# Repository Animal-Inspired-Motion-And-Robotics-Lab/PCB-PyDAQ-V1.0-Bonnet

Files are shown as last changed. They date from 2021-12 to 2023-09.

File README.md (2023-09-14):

# Raspberry Pi Data Conversion Board (ADC, DAC, PWM)

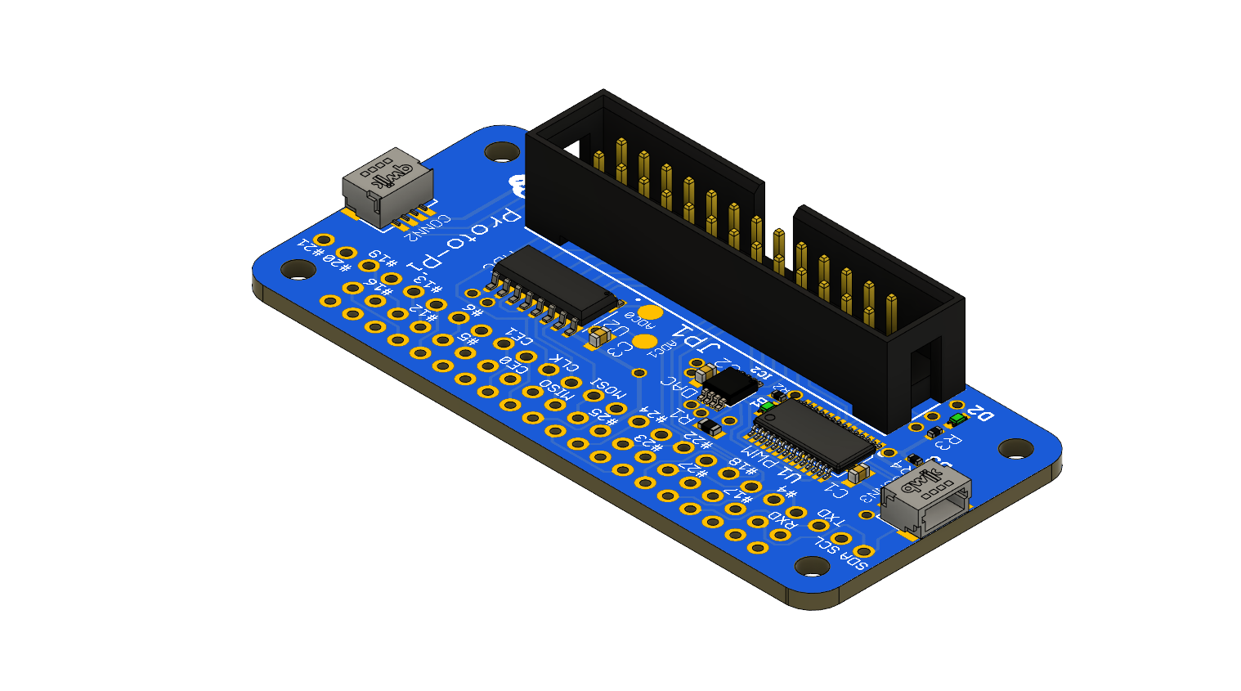
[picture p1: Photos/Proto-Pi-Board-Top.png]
<br/>
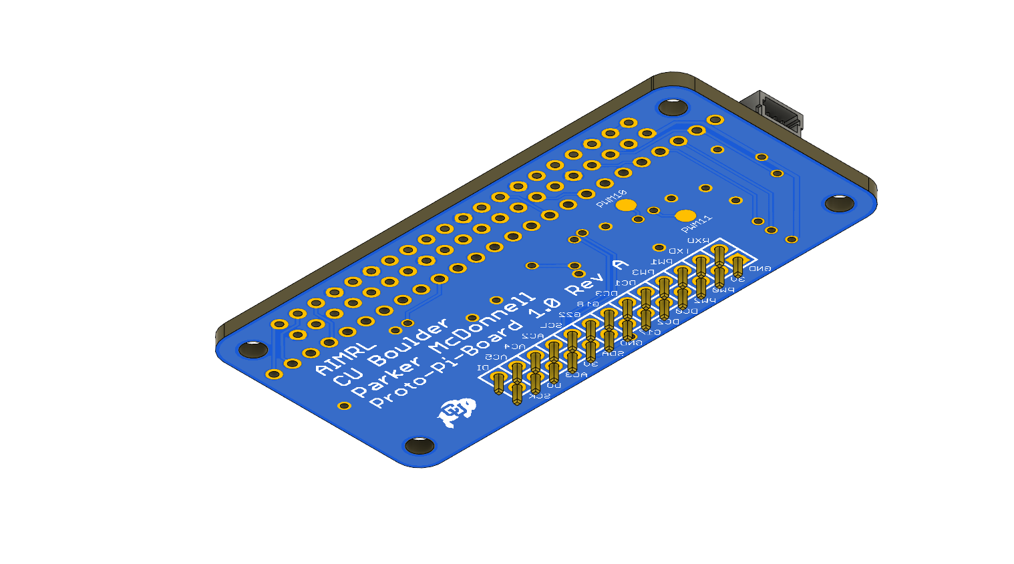
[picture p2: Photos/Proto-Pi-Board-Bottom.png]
<br/>

## Description

This board turns your Raspberry Pi into a prototyping powerhouse!  Now your Raspberry Pi can both read and generate analog voltages, in addition to driving PWM waveforms all using existing Python libraries! This repository includes all design files needed to immediately order and assemble the board or make further modifications!

## Features

- 26 Pin IDC Connector for easy prototyping
- 2x STEMMA QT compatible connectors (I2C, +3.3V and GND)
- 4x 12 bit ADC, DAC and PWM channels
- Easy access to SPI, I2C, UART and GPIO
- 2x general purpose PWM controlled LEDs 

## Pinout

### JP1 Connector Pinout <br/> <br/>

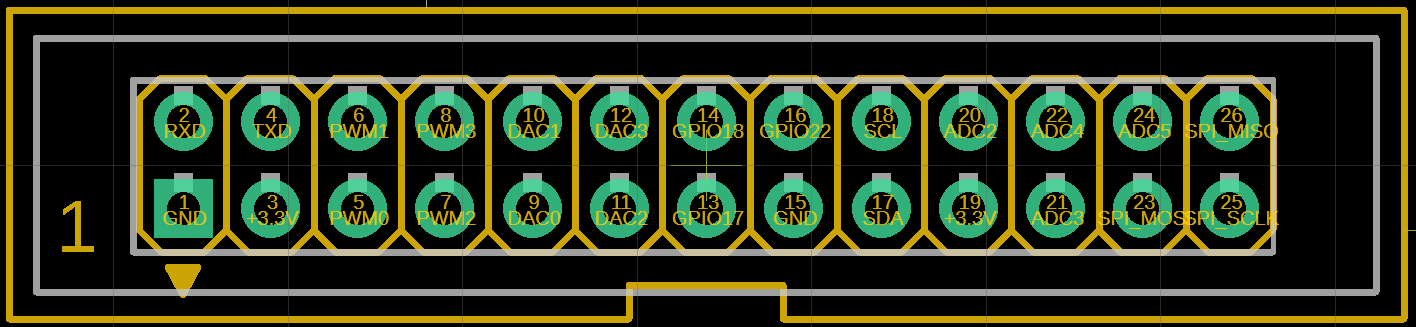
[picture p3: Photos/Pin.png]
<br/> <br/>

| Pin | Signal
| --- | --- |
|1	|GND|
|2	|RXD 
|3	|+3.3V 
|4	|TXD | 
|5	|PWM0
|6	|PWM1
|7	|PWM2
|8	|PWM3
|9	|DAC0
|10	|DAC1
|11	|DAC2
|12	|DAC3
|13	|GPIO17
|14	|GPIO18
|15	|GND
|16	|GPIO22
|17	|SDA
|18	|SCL
|19	|+3.3V
|20	|ADC2
|21	|ADC3
|22	|ADC4
|23	|SPI_MOSI
|24	|ADC5
|25	|SPI_SCLK
|26	|SPI_MISO

## Python Drivers <br/> <br/>

The Proto-Pi board uses Python based drivers to control the ADC, DAC and PWM integrated circuits.  Make sure to install the Adafruit CircuitPython, and required dependencies [(instructions)](https://learn.adafruit.com/circuitpython-on-raspberrypi-linux/installing-circuitpython-on-raspberry-pi) before installing the following drivers: 

- [MCP4728](https://github.com/adafruit/Adafruit_CircuitPython_MCP4728) (12-bit, Quad DAC)
- [MCP3008](https://pypi.org/project/adafruit-circuitpython-mcp3xxx/ )  (10-bit, 8-Channel ADC )
- [PCA9685](https://github.com/adafruit/Adafruit_CircuitPython_PCA9685) (12-bit, 16-Channel PWM)

## Datasheets!

- [MCP4728](http://ww1.microchip.com/downloads/en/devicedoc/22187e.pdf) (12-bit, Quad DAC)
- [MCP3008](https://ww1.microchip.com/downloads/en/DeviceDoc/21295d.pdf)  (10-bit, 8-Channel ADC )
- [PCA9685](https://www.nxp.com/docs/en/data-sheet/PCA9685.pdf) (12-bit, 16-Channel PWM)

## License

The original board shape and connector pinout was based on the amazing [Adafruit Prototype Bonnet](https://www.adafruit.com/product/3203). Thanks Adafruit!

This work is licensed under the Creative Commons Attribution-ShareAlike 4.0 International License. To view a copy of this license, visit http://creativecommons.org/licenses/by-sa/4.0/ or send a letter to Creative Commons, PO Box 1866, Mountain View, CA 94042, USA.

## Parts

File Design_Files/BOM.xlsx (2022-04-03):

Line Item | Reference Designator | Package | Value | Part Number | Mouser PN
1 | JP1 | 2.54mm 2X13 Female IDC Connector | CONNECTOR | 2x13 ICD Connetor (https://www.amazon.com/gp/product/B07DK22HNK/ref=ppx_yo_dt_b_asin_title_o02_s00?ie=UTF8&psc=1) | NA
2 | D1, D2, D3 | 603 | Green LED | SML-D12P8WT86C | 755-SML-D12P8WT86C (https://www.mouser.com/ProductDetail/755-SML-D12P8WT86C)
3 | R2, R3, R4 | 402 | 10Kohm | any | any
4 | C1, C2, C3 | 603 | .1uF | any | any
5 | R1 | 603 | 10K | any | any
6 | U2 | SOIC-16 | ADC-MCP3008 | MCP3008-I/SL | 579-MCP3008-I/SL
9 | CONN1 | 2.54MM MALE PIN HEADER | CONNECTOR | any | any
10 | CONN2, CONN3 | JST_SH4 | CONNECTOR | 4208 | 485-4208
11 | IC2 | MSOP10 | DAC-MCP4728 | MCP4728A1T-E | 579-MCP4728A1T-E
12 | U1 | TSSOP28 | IC-PCA9685PW | PCA9685PW,118 | 771-PCA9685PW

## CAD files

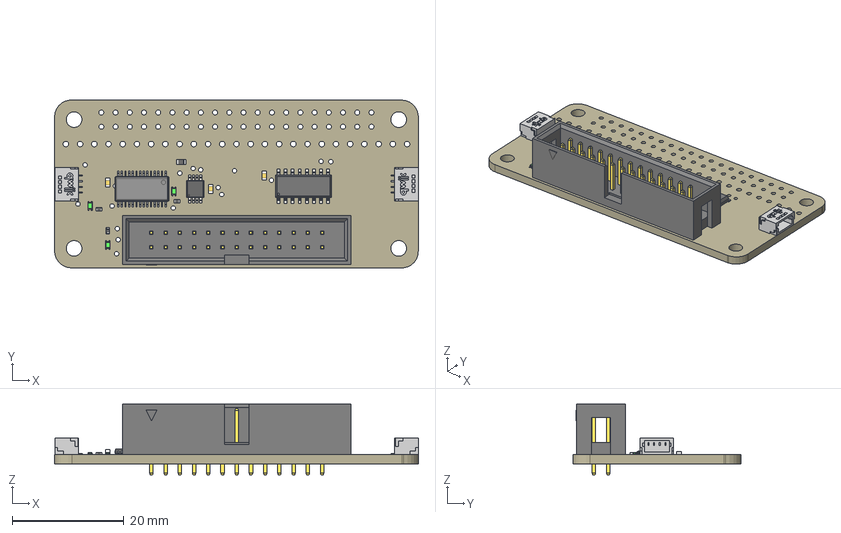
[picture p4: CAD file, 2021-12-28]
CAD/Proto-Pi-Board-1.0-Rev-A.step
65.0 x 30.0 x 12.6 mm
Board
R0402 x 3
CU_LOGO x 2
C0603 x 3
R0603
CHIPLED_0603_NOOUTLINE x 3
JST 4PIN WIRE SMD FEMALE CASE BOX x 2
JST 4PIN - FEMALE INSIDE PINS x 2
JST 4PIN WIRE SMD FEMALE QUICK LOGO x 2
JST 4PIN WIRE SMD FEMALE SOLDER PINS x 2
JST 4PIN WIRE SMD FEMALE SOLDER PADS 01 x 2
JST 4PIN WIRE SMD FEMALE SOLDER PADS 02 x 2
JST 4PIN WIRE SMD FEMALE CABLE COLOR x 8
MSOP10
PI_BONNET_NODIM
RASBERRYPI_IDC
TSSOP28-0.65-9.7X4.4MM

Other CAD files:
CAD/Proto-Pi-Board-1.0-Rev-A.f3d

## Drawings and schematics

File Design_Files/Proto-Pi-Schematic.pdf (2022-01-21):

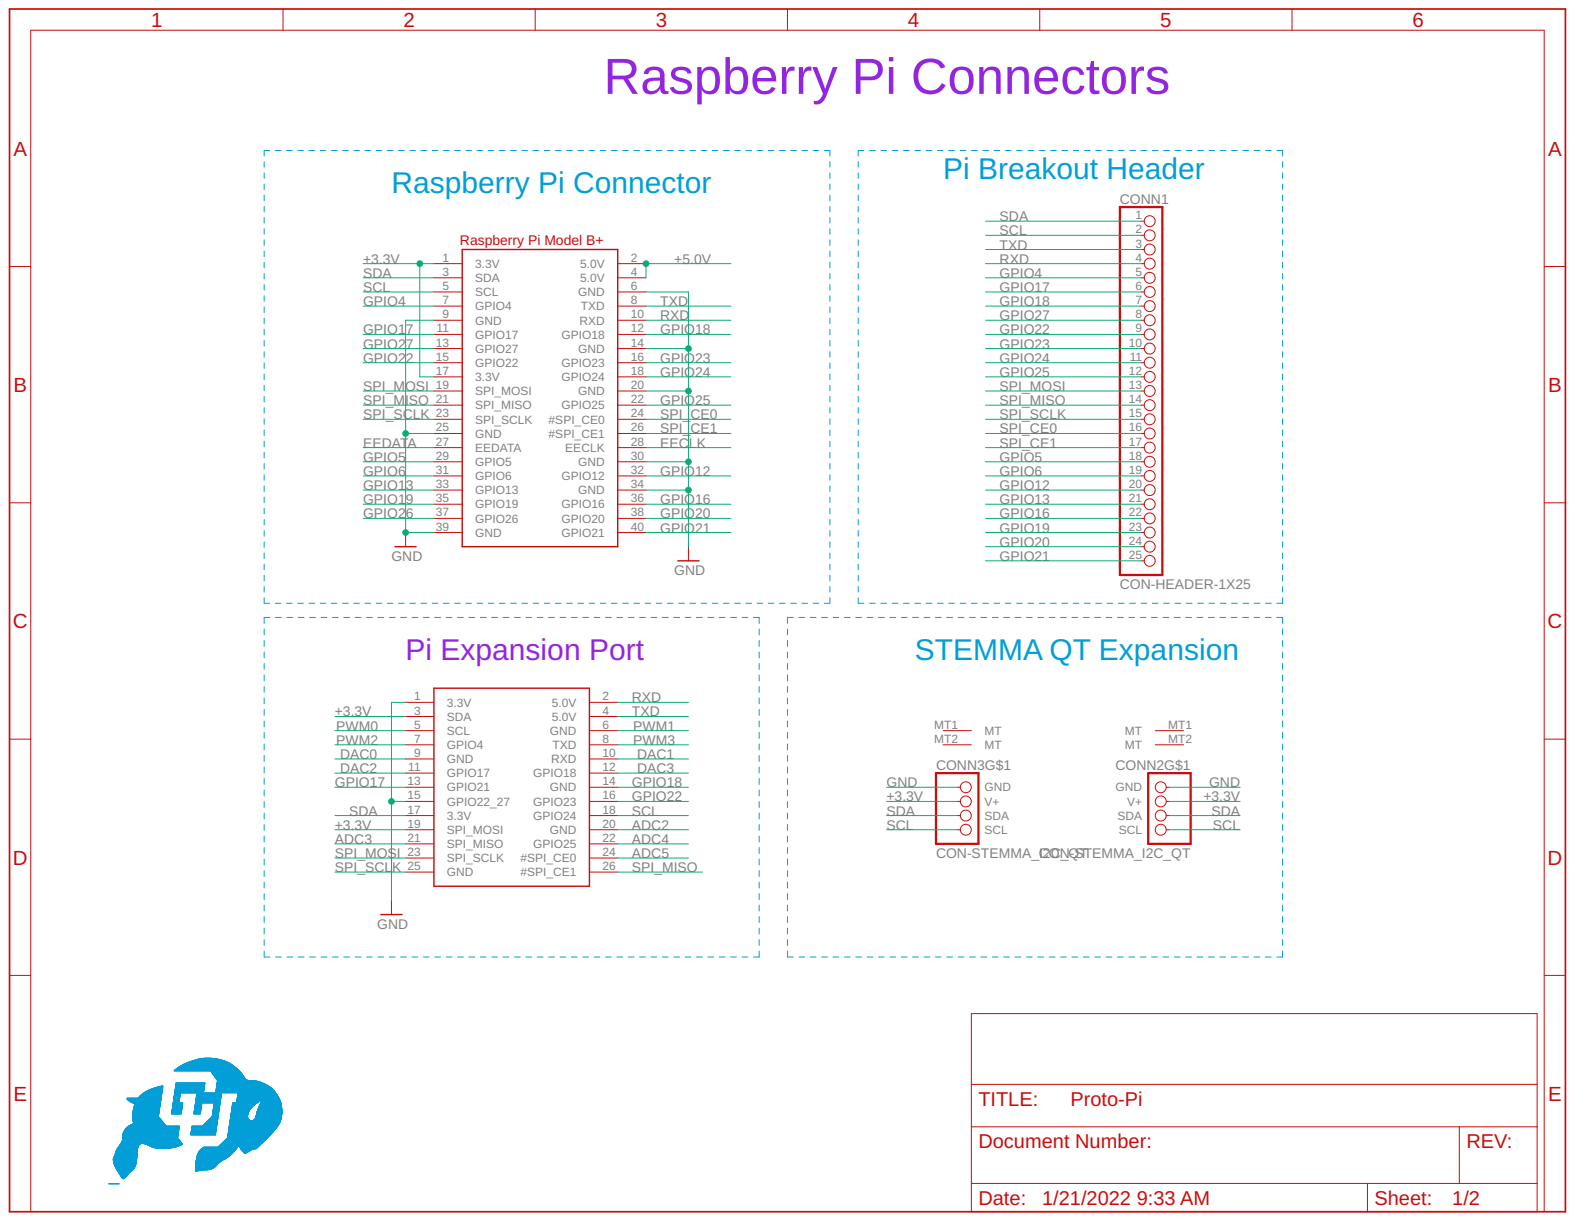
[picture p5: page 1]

Document Number: | REV:

Date: 1/21/2022 9:33 AM | Sheet: 1/2

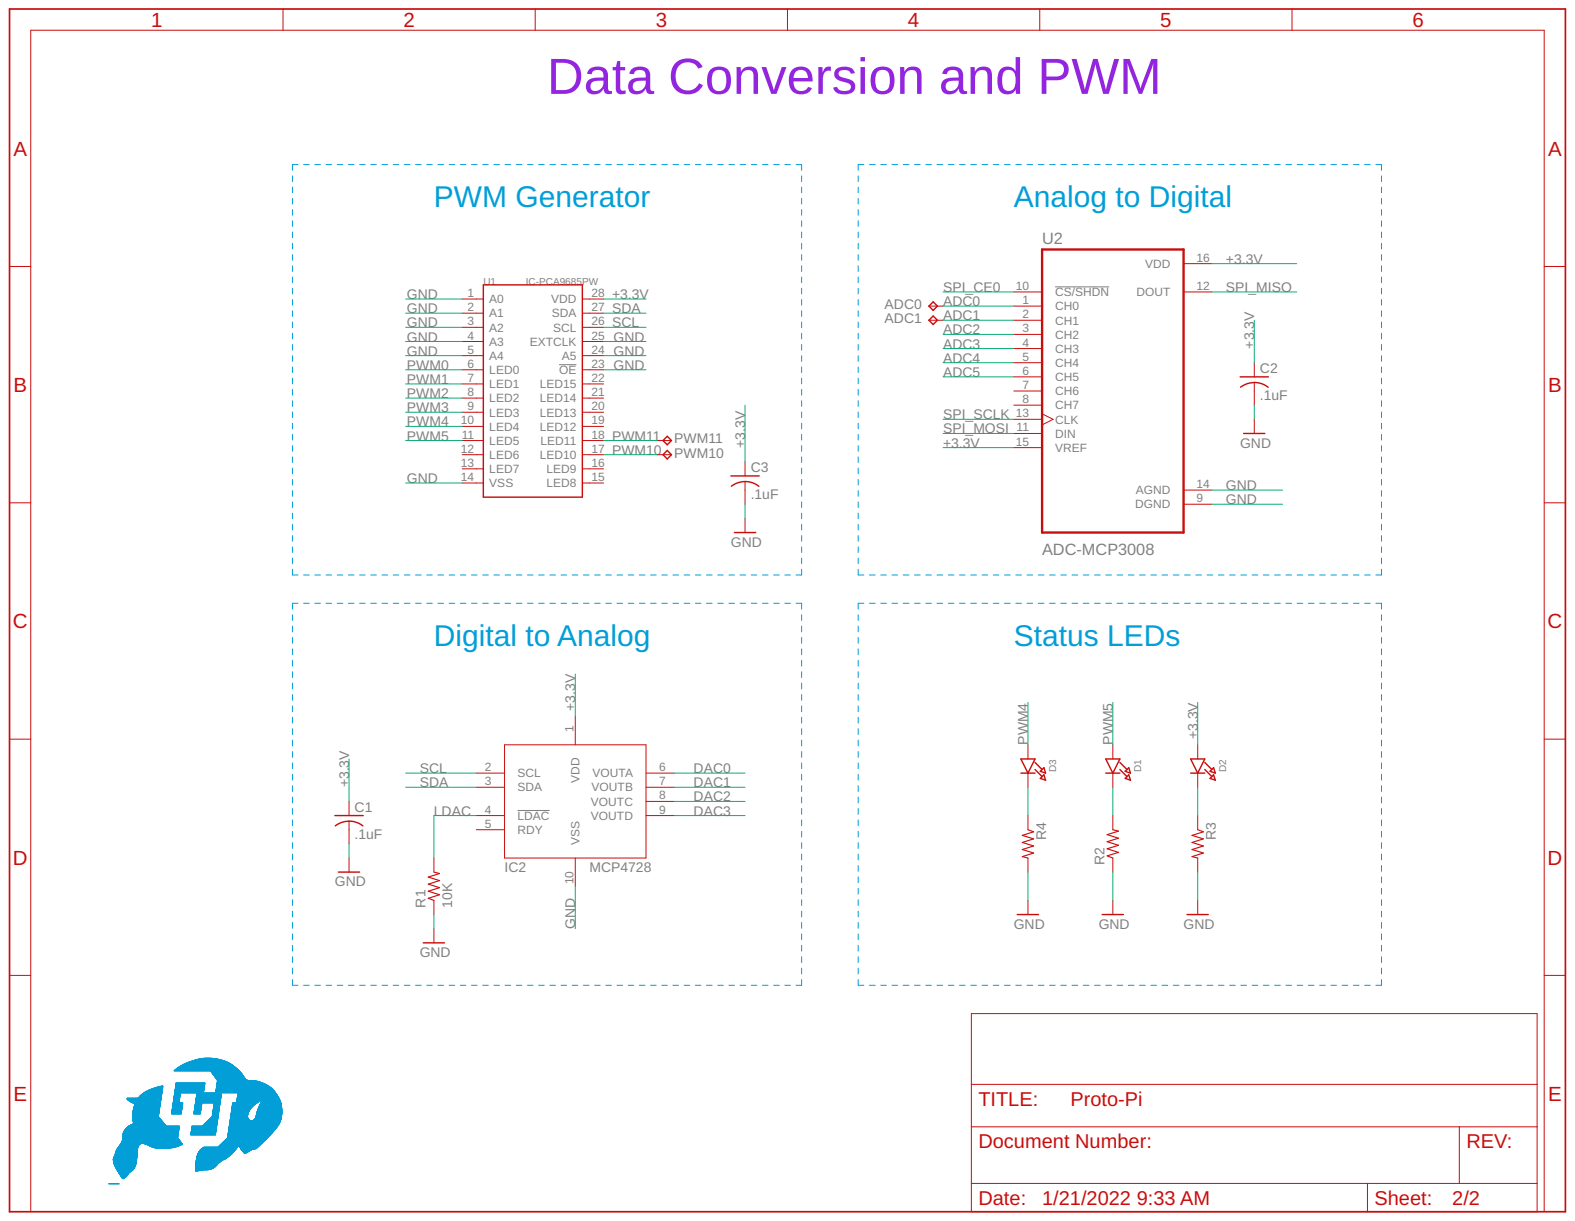
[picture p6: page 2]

Data Conversion and PWM

Document Number: | REV:

Date: 1/21/2022 9:33 AM | Sheet: 2/2

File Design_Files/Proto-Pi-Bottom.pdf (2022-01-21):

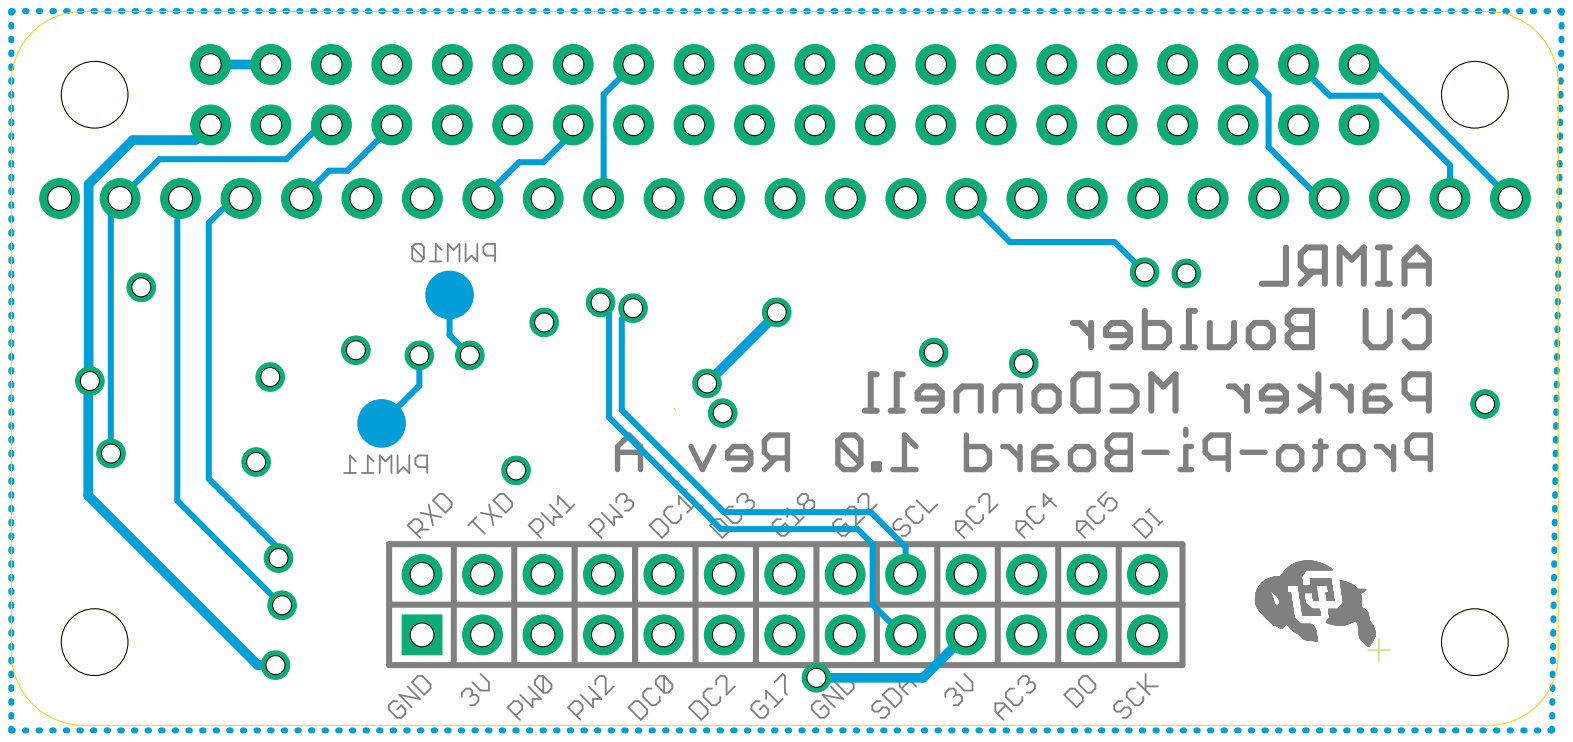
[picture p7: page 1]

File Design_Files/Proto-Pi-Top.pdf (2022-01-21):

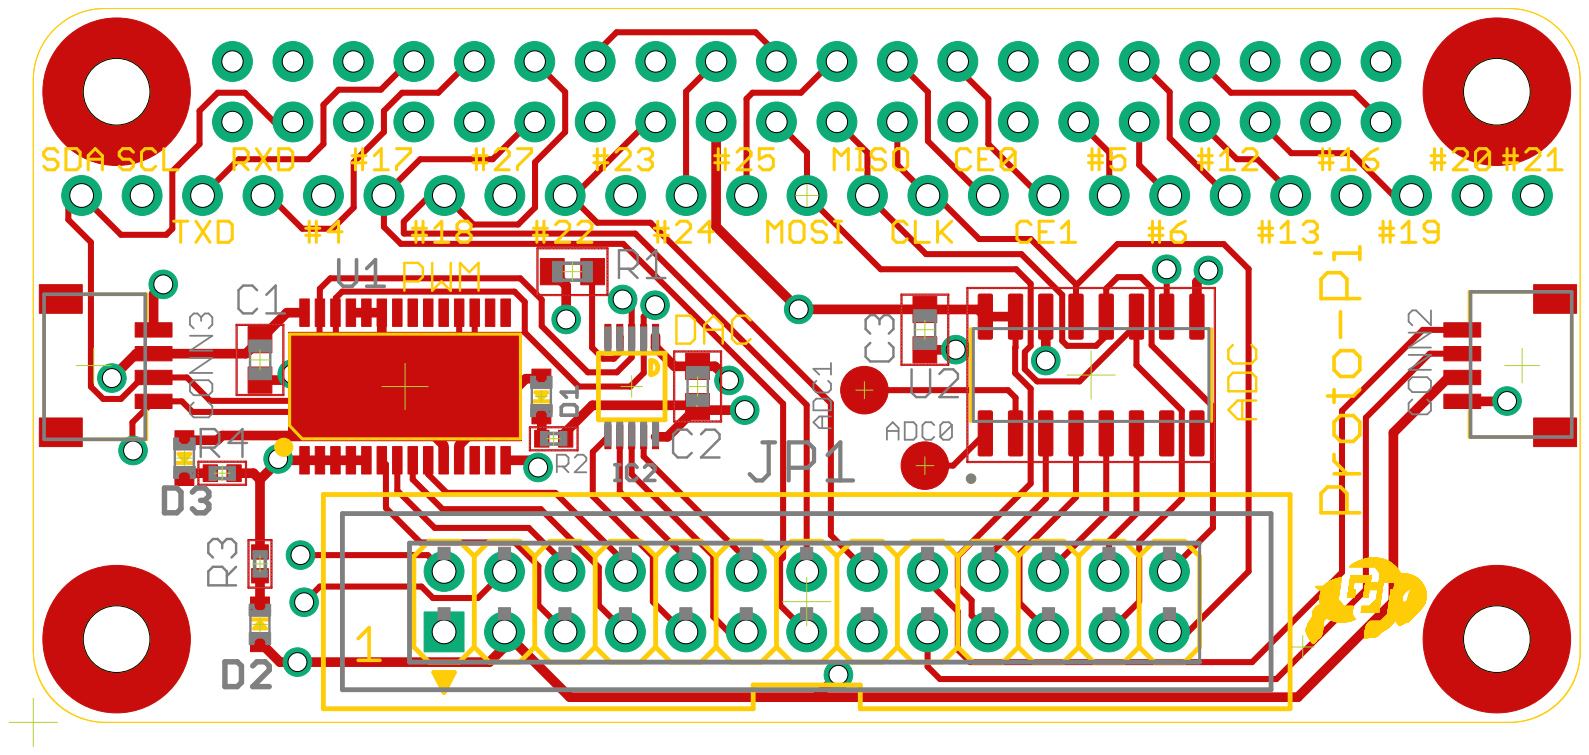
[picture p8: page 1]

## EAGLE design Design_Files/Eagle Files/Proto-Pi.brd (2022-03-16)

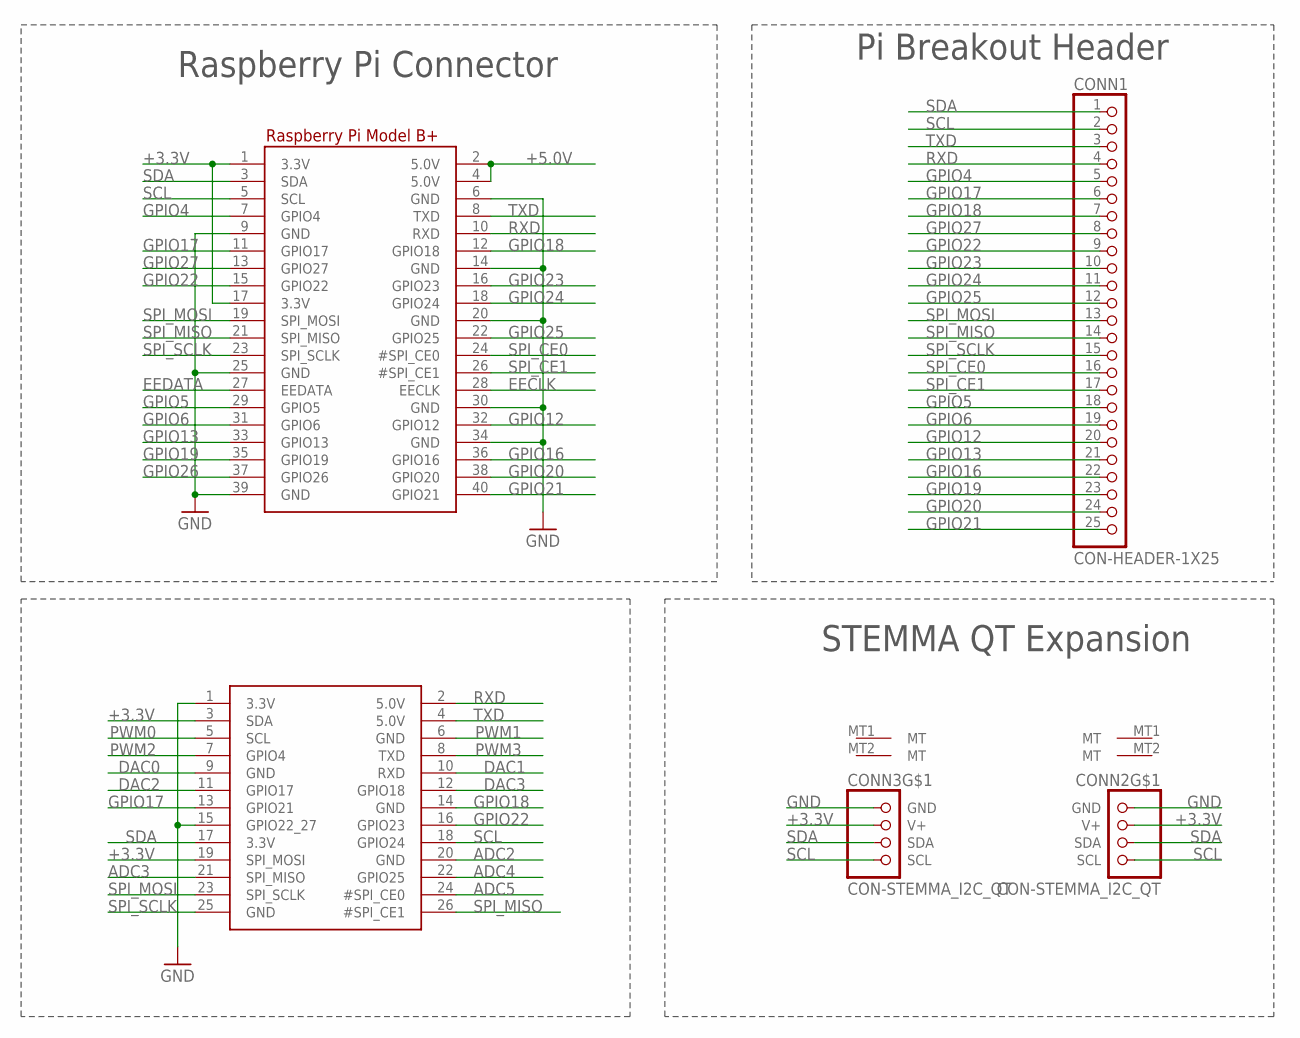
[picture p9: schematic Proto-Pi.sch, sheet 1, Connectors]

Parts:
CONN1: CON-HEADER-1X25; 1X25_ROUND_70MIL
CONN2, CONN3: CON-STEMMA_I2C_QT; JST_SH4
JP1: CON-RASBERRYPI_IDC; RASBERRYPI_IDC
P1: ART-CU-LOGO; CU_LOGO
RPI1: BRD-RASPBERRYPI_BPLUS_BONNETNODIM; PI_BONNET_NODIM

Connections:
+3.3V: CONN2.2 (V+), CONN3.2 (V+), JP1.3 (SDA), JP1.19 (SPI_MOSI), RPI1.1 (3.3V), RPI1.17 (3.3V); also elsewhere on the board
+5.0V: RPI1.2 (5.0V), RPI1.4 (5.0V)
ADC2: JP1.20 (GND); also elsewhere on the board
ADC3: JP1.21 (SPI_MISO); also elsewhere on the board
ADC4: JP1.22 (GPIO25); also elsewhere on the board
ADC5: JP1.24 (#SPI_CE0); also elsewhere on the board
DAC0: JP1.9 (GND); also elsewhere on the board
DAC1: JP1.10 (RXD); also elsewhere on the board
DAC2: JP1.11 (GPIO17); also elsewhere on the board
DAC3: JP1.12 (GPIO18); also elsewhere on the board
EECLK: RPI1.28 (EECLK)
EEDATA: RPI1.27 (EEDATA)
GND: CONN2.1 (GND), CONN3.1 (GND), JP1.1 (3.3V), JP1.15 (GPIO22_27), RPI1.6 (GND), RPI1.9 (GND), RPI1.14 (GND), RPI1.20 (GND), RPI1.25 (GND), RPI1.30 (GND), RPI1.34 (GND), RPI1.39 (GND); also elsewhere on the board
GPIO4: CONN1.5, RPI1.7 (GPIO4)
GPIO5: CONN1.18, RPI1.29 (GPIO5)
GPIO6: CONN1.19, RPI1.31 (GPIO6)
GPIO12: CONN1.20, RPI1.32 (GPIO12)
GPIO13: CONN1.21, RPI1.33 (GPIO13)
GPIO16: CONN1.22, RPI1.36 (GPIO16)
GPIO17: CONN1.6, JP1.13 (GPIO21), RPI1.11 (GPIO17)
GPIO18: CONN1.7, JP1.14 (GND), RPI1.12 (GPIO18)
GPIO19: CONN1.23, RPI1.35 (GPIO19)
GPIO20: CONN1.24, RPI1.38 (GPIO20)
GPIO21: CONN1.25, RPI1.40 (GPIO21)
GPIO22: CONN1.9, JP1.16 (GPIO23), RPI1.15 (GPIO22)
GPIO23: CONN1.10, RPI1.16 (GPIO23)
GPIO24: CONN1.11, RPI1.18 (GPIO24)
GPIO25: CONN1.12, RPI1.22 (GPIO25)
GPIO26: RPI1.37 (GPIO26)
GPIO27: CONN1.8, RPI1.13 (GPIO27)
PWM0: JP1.5 (SCL); also elsewhere on the board
PWM1: JP1.6 (GND); also elsewhere on the board
PWM2: JP1.7 (GPIO4); also elsewhere on the board
PWM3: JP1.8 (TXD); also elsewhere on the board
RXD: CONN1.4, JP1.2 (5.0V), RPI1.10 (RXD)
SCL: CONN1.2, CONN2.4 (SCL), CONN3.4 (SCL), JP1.18 (GPIO24), RPI1.5 (SCL); also elsewhere on the board
SDA: CONN1.1, CONN2.3 (SDA), CONN3.3 (SDA), JP1.17 (3.3V), RPI1.3 (SDA); also elsewhere on the board
SPI_CE0: CONN1.16, RPI1.24 (#SPI_CE0); also elsewhere on the board
SPI_CE1: CONN1.17, RPI1.26 (#SPI_CE1)
SPI_MISO: CONN1.14, JP1.26 (#SPI_CE1), RPI1.21 (SPI_MISO); also elsewhere on the board
SPI_MOSI: CONN1.13, JP1.23 (SPI_SCLK), RPI1.19 (SPI_MOSI); also elsewhere on the board
SPI_SCLK: CONN1.15, JP1.25 (GND), RPI1.23 (SPI_SCLK); also elsewhere on the board
TXD: CONN1.3, JP1.4 (5.0V), RPI1.8 (TXD)

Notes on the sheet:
Raspberry Pi Connector
Pi Breakout Header
STEMMA QT Expansion

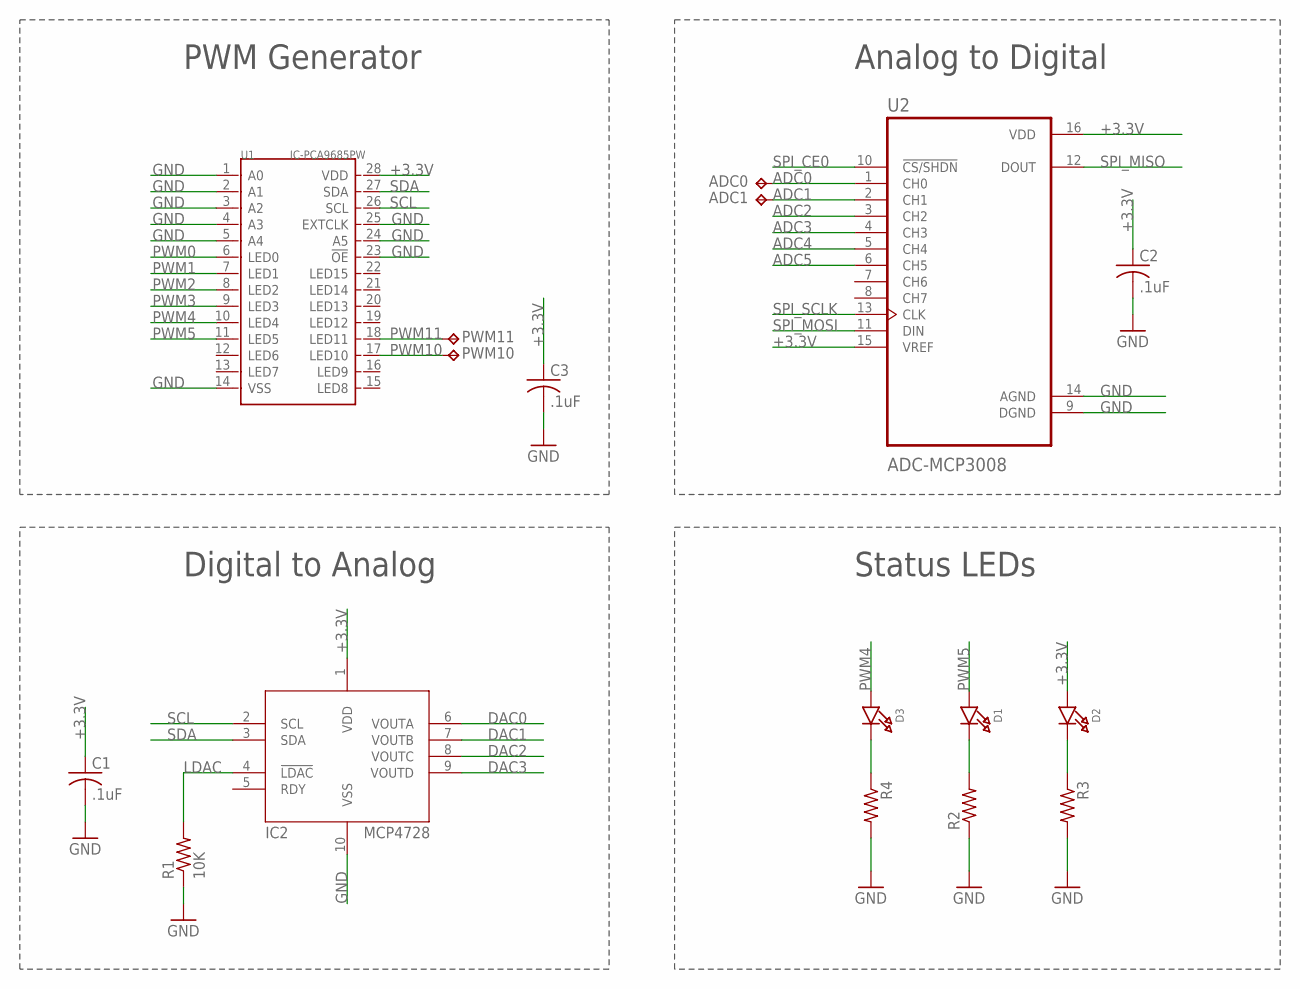
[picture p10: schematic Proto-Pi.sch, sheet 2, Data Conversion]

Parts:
ADC0, ADC1: TPTP20R; TP20R
C1, C2, C3: .1uF; C0603
D1, D2, D3: LED-SMA0603_NOOUTLINE; CHIPLED_0603_NOOUTLINE
IC2: DAC-MCP4728; MSOP10
P2: ART-CU-LOGO; CU_LOGO
PWM10, PWM11: TPTP20R; TP20R
R1: 10K; R0603
R2, R3, R4: R-US_R0402; R0402
U1: IC-PCA9685PW; TSSOP28-0.65-9.7X4.4MM
U2: ADC-MCP3008; SOIC127P600X175-16N

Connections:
+3.3V: C1.1, C2.1, C3.1, D2.A, IC2.1 (VDD), U1.28 (VDD), U2.15 (VREF), U2.16 (VDD); also elsewhere on the board
ADC0: ADC0.TP, U2.1 (CH0)
ADC1: ADC1.TP, U2.2 (CH1)
ADC2: U2.3 (CH2); also elsewhere on the board
ADC3: U2.4 (CH3); also elsewhere on the board
ADC4: U2.5 (CH4); also elsewhere on the board
ADC5: U2.6 (CH5); also elsewhere on the board
DAC0: IC2.6 (VOUTA); also elsewhere on the board
DAC1: IC2.7 (VOUTB); also elsewhere on the board
DAC2: IC2.8 (VOUTC); also elsewhere on the board
DAC3: IC2.9 (VOUTD); also elsewhere on the board
GND: C1.2, C2.2, C3.2, IC2.10 (VSS), R1.1, R2.1, R3.2, R4.2, U1.1 (A0), U1.2 (A1), U1.3 (A2), U1.4 (A3), U1.5 (A4), U1.14 (VSS), U1.23 (!OE), U1.24 (A5), U1.25 (EXTCLK), U2.9 (DGND), U2.14 (AGND); also elsewhere on the board
LDAC: IC2.4 (!LDAC), R1.2
unnamed: D1.C, R2.2
unnamed: D2.C, R3.1
unnamed: D3.C, R4.1
PWM0: U1.6 (LED0); also elsewhere on the board
PWM1: U1.7 (LED1); also elsewhere on the board
PWM2: U1.8 (LED2); also elsewhere on the board
PWM3: U1.9 (LED3); also elsewhere on the board
PWM4: D3.A, U1.10 (LED4)
PWM5: D1.A, U1.11 (LED5)
PWM10: PWM10.TP, U1.17 (LED10)
PWM11: PWM11.TP, U1.18 (LED11)
SCL: IC2.2 (SCL), U1.26 (SCL); also elsewhere on the board
SDA: IC2.3 (SDA), U1.27 (SDA); also elsewhere on the board
SPI_CE0: U2.10 (!CS/SHDN); also elsewhere on the board
SPI_MISO: U2.12 (DOUT); also elsewhere on the board
SPI_MOSI: U2.11 (DIN); also elsewhere on the board
SPI_SCLK: U2.13 (CLK); also elsewhere on the board

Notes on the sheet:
PWM Generator
Analog to Digital
Digital to Analog
Status LEDs

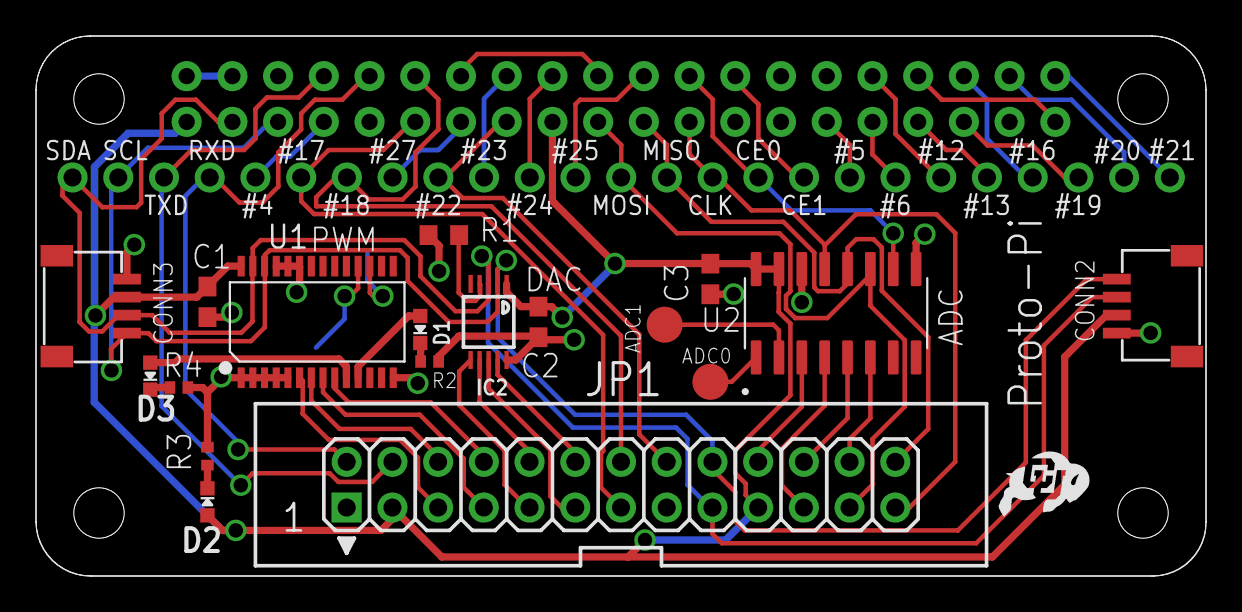
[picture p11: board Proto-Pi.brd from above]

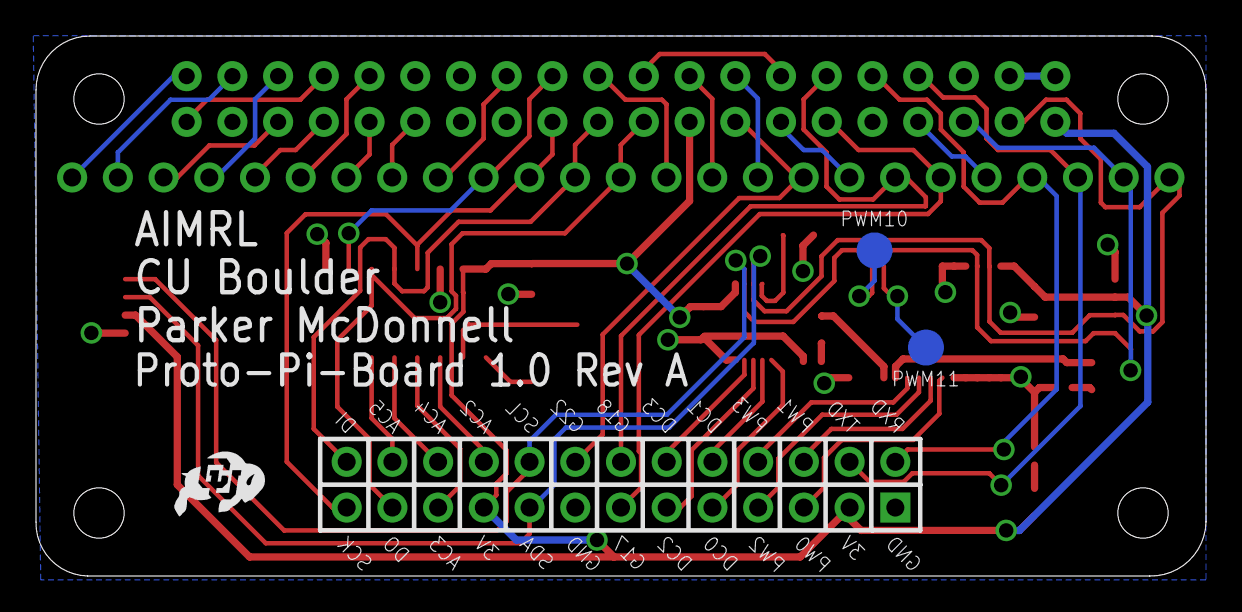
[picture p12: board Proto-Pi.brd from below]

Board: 2 copper layers, 65.0 x 30.0 mm, 24 parts (3 on the bottom side), 50 nets.

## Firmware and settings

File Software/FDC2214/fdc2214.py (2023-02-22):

from micropython import const
from adafruit_bus_device.i2c_device import I2CDevice
from math import pi

FDC2214_I2C_ADDR_0   =const(0x2A)
FDC2214_I2C_ADDR_1   =const(0x2B)
# Address is 0x2A (default) or 0x2B (if ADDR is high)

#bitmasks
FDC2214_CH0_UNREADCONV =const(0x0008)         #denotes unread CH0 reading in STATUS register
FDC2214_CH1_UNREADCONV =const(0x0004)         #denotes unread CH1 reading in STATUS register
FDC2214_CH2_UNREADCONV =const(0x0002)         #denotes unread CH2 reading in STATUS register
FDC2214_CH3_UNREADCONV =const(0x0001)         #denotes unread CH3 reading in STATUS register


#registers
FDC2214_DEVICE_ID            =const(0x7F)
FDC2214_MUX_CONFIG           =const(0x1B)
FDC2214_CONFIG               =const(0x1A)
FDC2214_RCOUNT_CH0           =const(0x08)
FDC2214_RCOUNT_CH1           =const(0x09)
FDC2214_RCOUNT_CH2           =const(0x0A)
FDC2214_RCOUNT_CH3           =const(0x0B)
FDC2214_OFFSET_CH0           =const(0x0C)
FDC2214_OFFSET_CH1           =const(0x0D)
FDC2214_OFFSET_CH2           =const(0x0E)
FDC2214_OFFSET_CH3           =const(0x0F)
FDC2214_SETTLECOUNT_CH0      =const(0x10)
FDC2214_SETTLECOUNT_CH1      =const(0x11)
FDC2214_SETTLECOUNT_CH2      =const(0x12)
FDC2214_SETTLECOUNT_CH3      =const(0x13)
FDC2214_CLOCK_DIVIDERS_CH0   =const(0x14)
FDC2214_CLOCK_DIVIDERS_CH1   =const(0x15)
FDC2214_CLOCK_DIVIDERS_CH2   =const(0x16)
FDC2214_CLOCK_DIVIDERS_CH3   =const(0x17)
FDC2214_STATUS               =const(0x18)
FDC2214_DATA_CH0_MSB         =const(0x00)
FDC2214_DATA_CH0_LSB         =const(0x01)
FDC2214_DATA_CH1_MSB         =const(0x02)
FDC2214_DATA_CH1_LSB         =const(0x03)
FDC2214_DATA_CH2_MSB         =const(0x04)
FDC2214_DATA_CH2_LSB         =const(0x05)
FDC2214_DATA_CH3_MSB         =const(0x06)
FDC2214_DATA_CH3_LSB         =const(0x07)
FDC2214_DRIVE_CH0            =const(0x1E)
FDC2214_DRIVE_CH1            =const(0x1F)
FDC2214_DRIVE_CH2            =const(0x20)
FDC2214_DRIVE_CH3            =const(0x21)

# mask for 28bit data to filter out flag bits
FDC2214_DATA_CHx_MASK_DATA          =const(0x0FFF) 
FDC2214_DATA_CHx_MASK_ERRAW         =const(0x1000) 
FDC2214_DATA_CHx_MASK_ERRWD         =const(0x2000) 

class FDC2214(object):
    """
    :param i2c: The `busio.I2C` object to use. This is the only required parameter.
    :param 
    # Class-level buffer to reduce allocations and fragmentation.
    # Note this is NOT thread-safe or re-entrant by design!   
    """
    _BUFFER = bytearray(8)
    def __init__(self, i2c, *, address=FDC2214_I2C_ADDR_0):

        # create iw2
        self._device = I2CDevice(i2c, address)
        # Check for valid chip ID (from datasheet)
        if self._read16(FDC2214_DEVICE_ID) not in (0x3055,0x3054):
            raise RuntimeError('Failed to find FD2214, check wiring!')
        else:
            print('FDC2214 detected! Setting up now')
            
        self._write16(FDC2214_MUX_CONFIG,         0x220D)
        self._write16(FDC2214_CONFIG,             0x9E01)
        self._write16(FDC2214_RCOUNT_CH0,         0xFFFF)
        self._write16(FDC2214_RCOUNT_CH1,         0xFFFF)
        self._write16(FDC2214_RCOUNT_CH2,         0xFFFF)
        self._write16(FDC2214_RCOUNT_CH3,         0xFFFF)
        self._write16(FDC2214_OFFSET_CH0,         0x0000)
        self._write16(FDC2214_OFFSET_CH1,         0x0000)
        self._write16(FDC2214_OFFSET_CH2,         0x0000)
        self._write16(FDC2214_OFFSET_CH3,         0x0000)
        self._write16(FDC2214_SETTLECOUNT_CH0,    0x0400)
        self._write16(FDC2214_SETTLECOUNT_CH1,    0x0400)
        self._write16(FDC2214_SETTLECOUNT_CH2,    0x0400)
        self._write16(FDC2214_SETTLECOUNT_CH3,    0x0400)
        self._write16(FDC2214_CLOCK_DIVIDERS_CH0, 0x1001)
        self._write16(FDC2214_CLOCK_DIVIDERS_CH1, 0x1001)
        self._write16(FDC2214_CLOCK_DIVIDERS_CH2, 0x1001)
        self._write16(FDC2214_CLOCK_DIVIDERS_CH3, 0x1001)
        self._write16(FDC2214_DRIVE_CH0,          0x8C40)
        self._write16(FDC2214_DRIVE_CH1,          0x8C40)
        self._write16(FDC2214_DRIVE_CH2,          0x8C40)
        self._write16(FDC2214_DRIVE_CH3,          0x8C40)
        self._Fsense = self._Csense = 0
        self._channel = 3
        self._MSB = FDC2214_DATA_CH2_MSB
        self._LSB = FDC2214_DATA_CH2_LSB

    @property
    def channel(self):
        return self._channel

    @channel.setter
    def channel(self, channel=2):
        if channel not in (0,1,2,3,10,23):
            raise ValueError("Unsupported channel.")
        if channel == 0:
            self._write16(FDC2214_MUX_CONFIG, 0x020D)
            self._write16(FDC2214_CONFIG,     0x1E01)
            self._MSB = FDC2214_DATA_CH0_MSB
            self._LSB = FDC2214_DATA_CH0_LSB
        if channel == 1:
            self._write16(FDC2214_MUX_CONFIG, 0x020D)
            self._write16(FDC2214_CONFIG,     0x5E01)
            self._MSB = FDC2214_DATA_CH1_MSB
            self._LSB = FDC2214_DATA_CH1_LSB
        if channel == 2:
            self._write16(FDC2214_MUX_CONFIG, 0x220D)
            self._write16(FDC2214_CONFIG,     0x9E01)
            self._MSB = FDC2214_DATA_CH2_MSB
            self._LSB = FDC2214_DATA_CH2_LSB
        if channel == 3:
            self._write16(FDC2214_MUX_CONFIG, 0x420D)
            self._write16(FDC2214_CONFIG,     0xDE01)
            self._MSB = FDC2214_DATA_CH3_MSB
            self._LSB = FDC2214_DATA_CH3_LSB
        if channel == 10:
            self._write16(FDC2214_MUX_CONFIG, 0x820D)
            self._write16(FDC2214_CONFIG,     0x1E01)
        if channel == 23:
            self._write16(FDC2214_MUX_CONFIG, 0xC20D)
            self._write16(FDC2214_CONFIG,     0x1E01)

        self._channel = channel

    def _read_into(self, address, buf, count=None):
        # Read bytes from the specified address into the provided buffer.
        # If count is not specified (the default) the entire buffer is filled,
        # otherwise only count bytes are copied in.
        assert len(buf) > 0
        if count is None:
            count = len(buf)
        with self._device as i2c:
            i2c.write_then_readinto(bytes([address & 0xFF]), buf,
                                    in_end=count) #, #stop=False)    
    def _read16(self, address):
        # Read a 16-bit unsigned value for from the specified address.
        self._read_into(address, self._BUFFER, count=2)
        return self._BUFFER[0] << 8 | self._BUFFER[1]

    def _write16(self, address, value):
        # Rrite a 16-bit unsigned value to the specified address.
        with self._device as i2c:
            self._BUFFER[0] = address & 0xFF
            self._BUFFER[1] = (value >> 8) & 0xFF
            i2c.write(self._BUFFER, end=2)

    def _read_raw(self):
        _reading = (self._read16(self._MSB) & FDC2214_DATA_CHx_MASK_DATA) << 16
        _reading |= self._read16(self._LSB)
        return _reading
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

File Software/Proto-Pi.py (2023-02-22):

#import required modules
import board
import busio
import digitalio
import time

from board import SCL, SDA

# Documentation for drivers

# https://docs.circuitpython.org/projects/mcp4728/en/latest/api.html#implementation-notes
# https://docs.circuitpython.org/projects/mcp3xxx/en/latest/
# https://docs.circuitpython.org/projects/pca9685/en/latest/

#import drivers for ICs that are on the Proto-Pi
import adafruit_mcp4728
import adafruit_mcp3xxx.mcp3008 as MCP
from adafruit_mcp3xxx.analog_in import AnalogIn
from adafruit_pca9685 import PCA9685

# Create the I2C bus interface.
i2c_bus = busio.I2C(SCL, SDA)

## Create the SPI bus interface
spi = busio.SPI(clock=board.SCK, MISO=board.MISO, MOSI=board.MOSI)
# set chip select to 
cs = digitalio.DigitalInOut(board.D5) 

## Setup and configure PWM IC (PCA9685)
pwm = PCA9685(i2c_bus)
# Set the PWM frequency to 150 Hz.
pwm.frequency = 150

## Setup and configure DAC IC (MCP4728)
dac =  adafruit_mcp4728.MCP4728(i2c_bus)

## Setup and configure the ADAC
adc = MCP.MCP3008(spi, cs)
# create an analog input channel on pin 0
adc2 = AnalogIn(adc, MCP.P2)
adc3 = AnalogIn(adc, MCP.P3)
# Add additional channels here


### Example code to test functionality

# turn on red LED 
pwm.channels[5].duty_cycle = 0xF000

# set DAC outputs and saves settings
dac.channel_a.value = 0#65535 # Voltage = VDD
dac.channel_b.value = 0#int(65535/2) # VDD/2
dac.channel_c.value = 0 # VDD/4
dac.channel_d.value = 0 # 0V

# read from ADC 

print('Raw ADC Value: ', adc2.value)
print('ADC Voltage: ' + str(adc2.voltage) + 'V')
print('Raw ADC Value: ', adc3.value)
print('ADC Voltage: ' + str(adc3.voltage) + 'V')

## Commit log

2021-12-27 Big Commit!
    Updated the readme, added design files, photos and 3D CAD
    [Proto-Pi-1.0-Rev-A.f3d, Proto-Pi-1.0-Rev-A.step, Proto-Pi.brd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]
2021-12-28 Updated the design, created new photos and CAD
    [Proto-Pi-1.0-Rev-A.f3d, Proto-Pi-1.0-Rev-A.step, Proto-Pi-Board-1.0-Rev-A.f3d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]
2022-01-21 Created soldermask top stencil and PDFs for layout and schematic
    [solderpaste_top.gbr]
2022-03-13 added BOM, pinout and datasheets
    [Pinout.xlsx, Proto-Pi-BOM.csv, Proto-Pi-BOM.xlsx]
2022-03-16 Major Update
    Added picture of JP1 connector, and added pinout to readme.
    [Pinout.xlsx, Proto-Pi-BOM.xlsx, Proto-Pi.brd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]
2022-04-03 Created Altium library
    [Pinout.xlsx, Proto-Pi.Library.PrjPcb, Proto-Pi.PCBLIB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]
2022-04-03 Updated BOM and readme
    [Proto-Pi-BOM.xlsx]
2022-04-04 Added CAM outputs
    [BOM.xlsx, Proto-Pi-BOM.csv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]
2022-04-04 added stuff
    [Solderpaste_Stencil_(No_Outline).gbr, Solderpaste_Stencil_(Outline).gbr]
2022-04-09 Update README.md
    Added links to documentation and drivers for the ADC, DAC and PWM ICs.
2022-04-14 created drill files
    [profile_no_holes.gbr]
2023-09-07 Adjusted folder paths and added MCP3008 datasheet and orderable fabrication files all zipped up.
    [BOM.xlsx, Pinout.xlsx, Proto-Pi.Library.PrjPcb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]
2023-09-07 Updated readme with credit to Adafruit for original PCB outline
